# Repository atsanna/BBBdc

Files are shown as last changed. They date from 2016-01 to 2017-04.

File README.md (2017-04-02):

# BeagleBone Black Door Cape
This is a BeagleBone Black Cape designed for electronically locking or
unlocking a single door.  It can control either a 12V door strike or
a 12V door magnet.

You can order this PCB from oshpark here: https://oshpark.com/shared_projects/fA7vdbq6

The cape has the following features:
* Dual relays to ensure door is closed if a relay fails
* opto-isolated GPIO inputs for detecting door status and/or relay failure
* Jumpers for configuring door strike or door magnet (NO/NC)
* on-board voltage regulator so BBB can be powered via 12V
* connectors for two external software controlled 12V lamps
* LED indicators for 12V, 5V, relay engagement, and external lamps
* 24C256 EEPROM w/ address configurable via jumpers
* headers for an RPi/Arduino-compatible realtime clock module

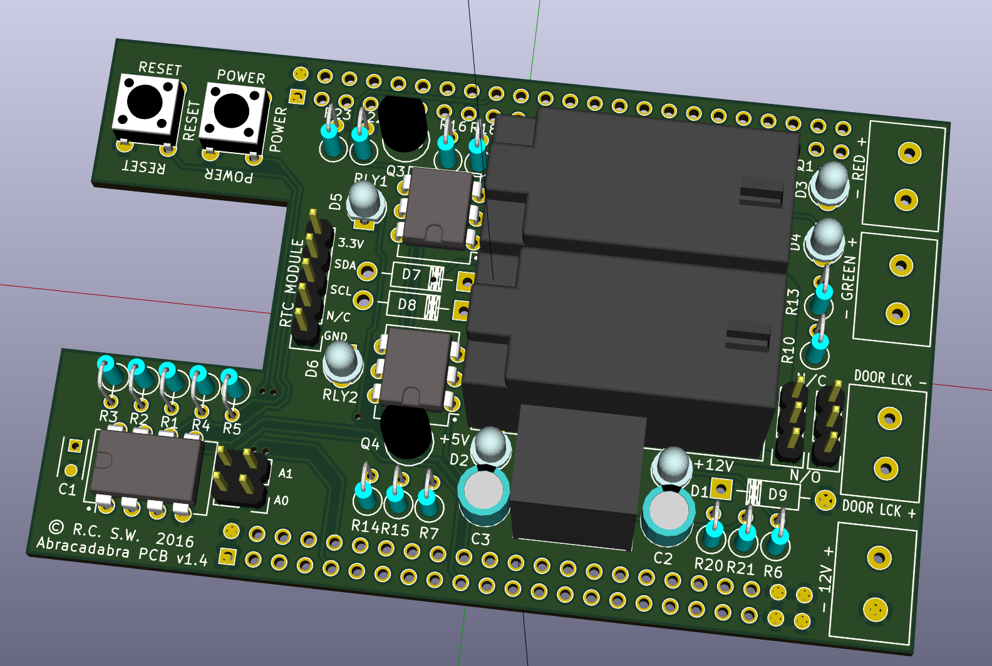
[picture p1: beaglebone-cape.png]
BareBone Cape


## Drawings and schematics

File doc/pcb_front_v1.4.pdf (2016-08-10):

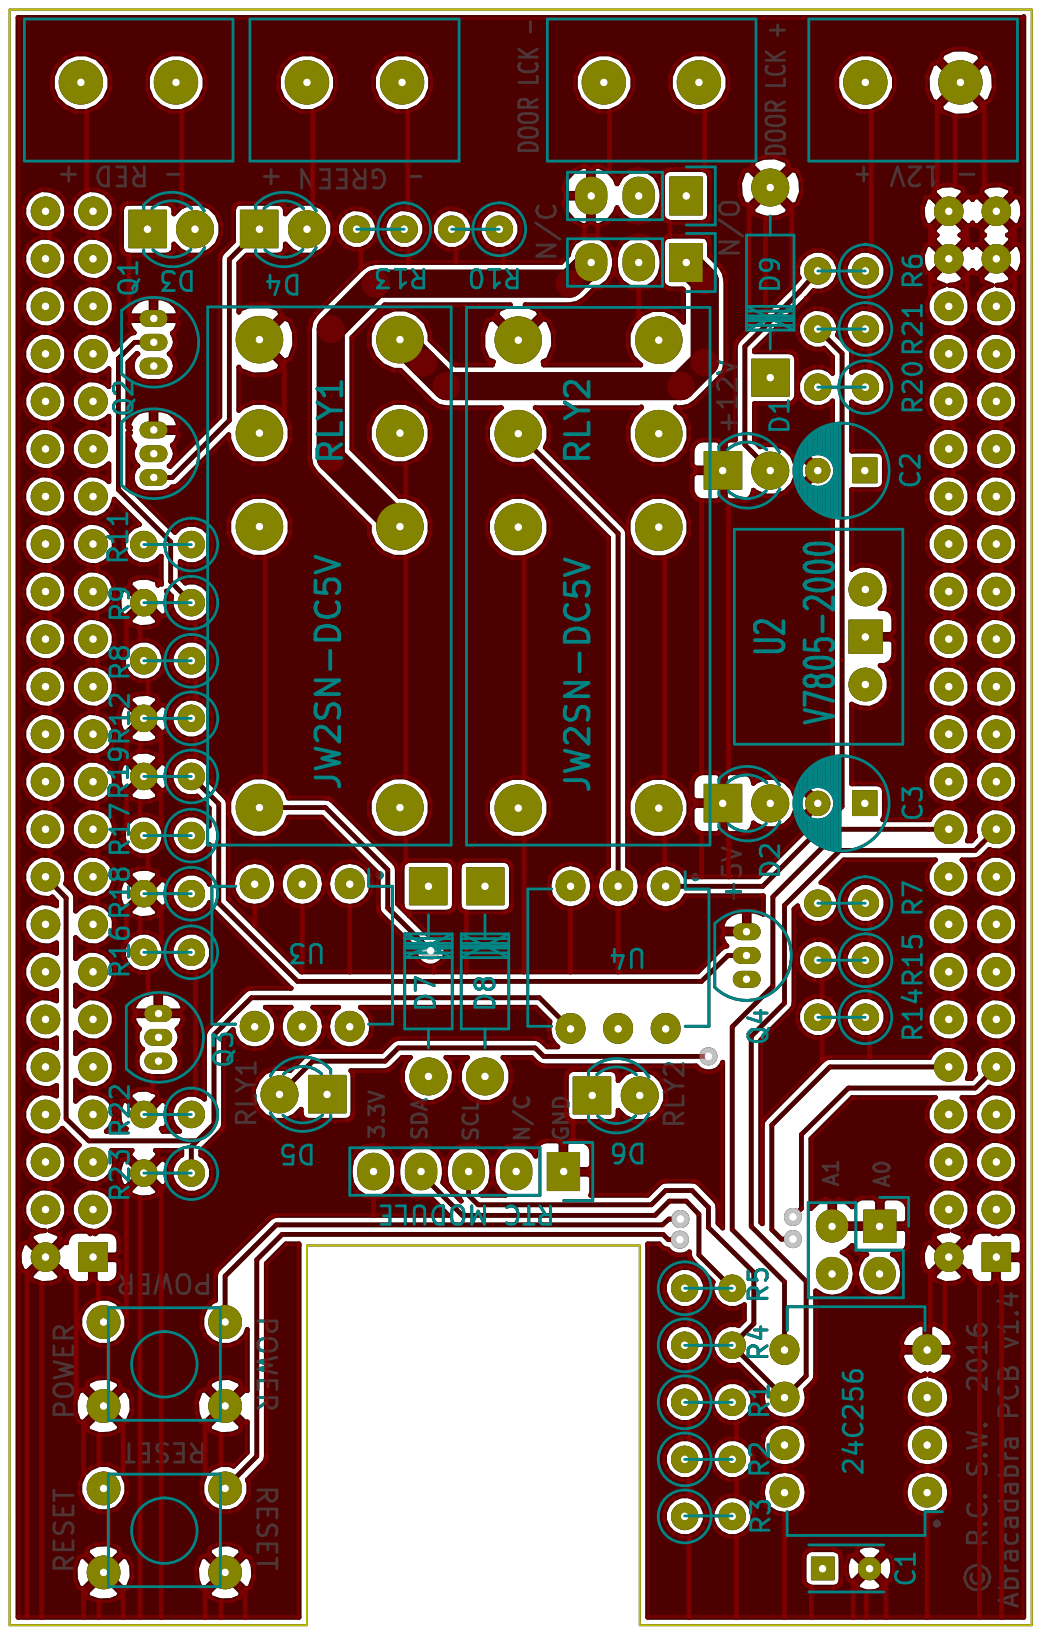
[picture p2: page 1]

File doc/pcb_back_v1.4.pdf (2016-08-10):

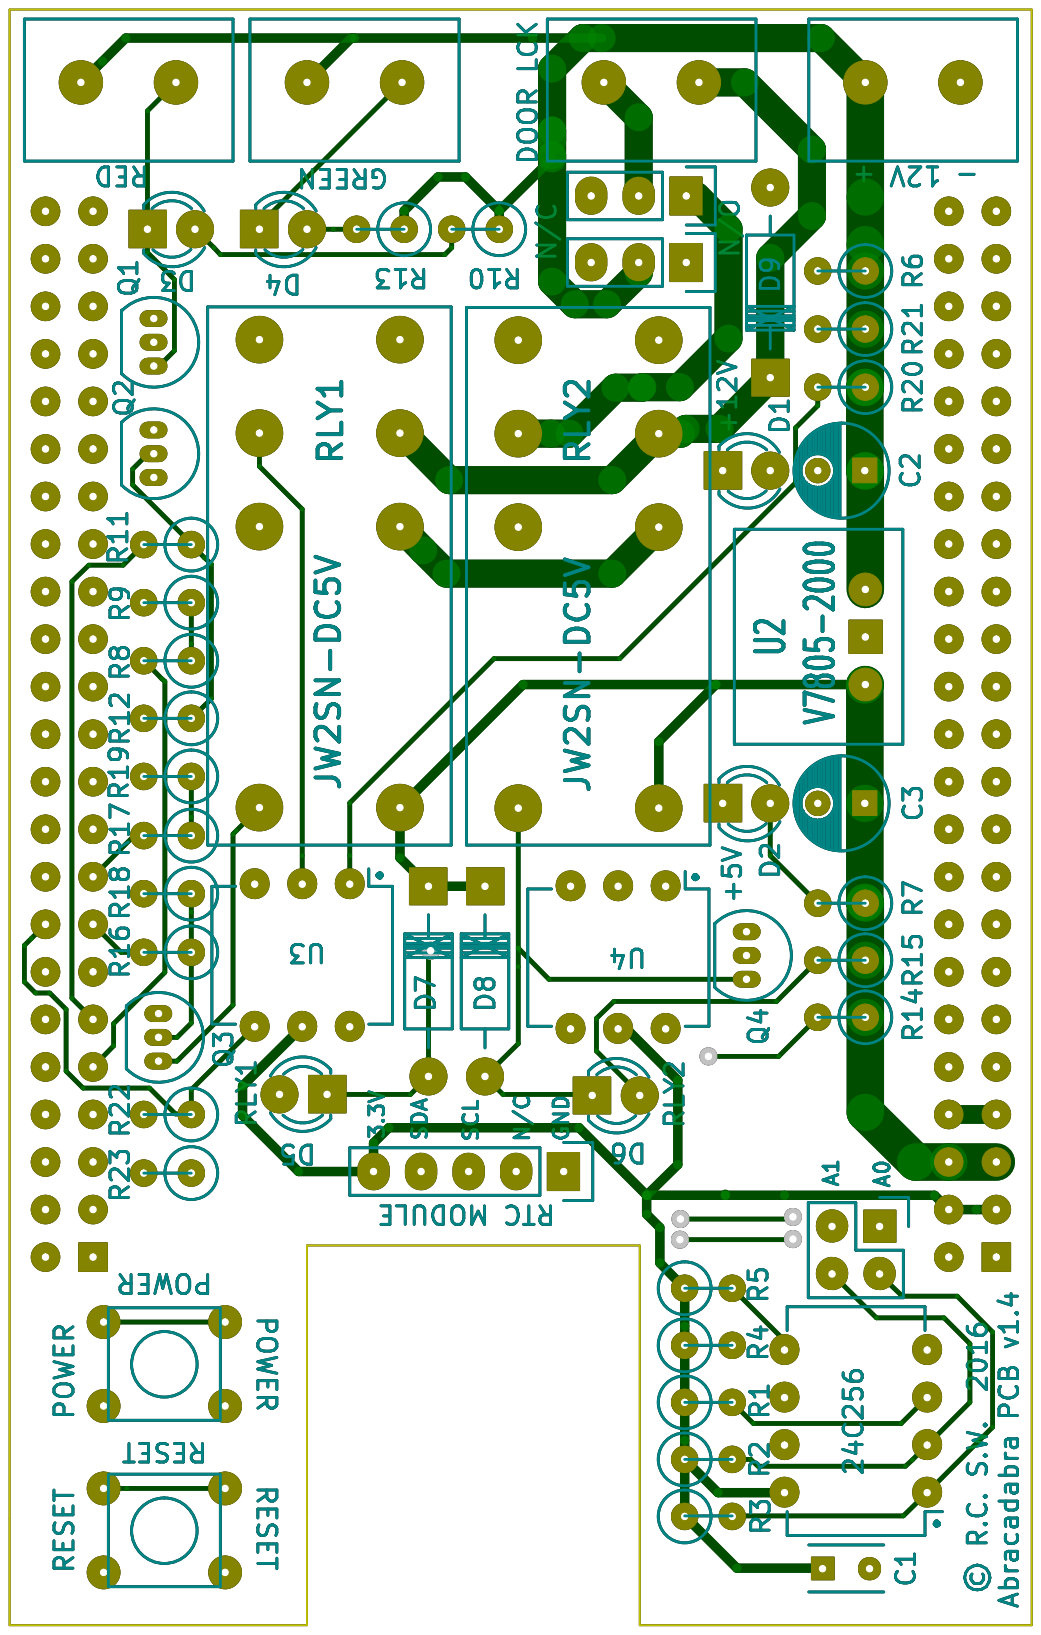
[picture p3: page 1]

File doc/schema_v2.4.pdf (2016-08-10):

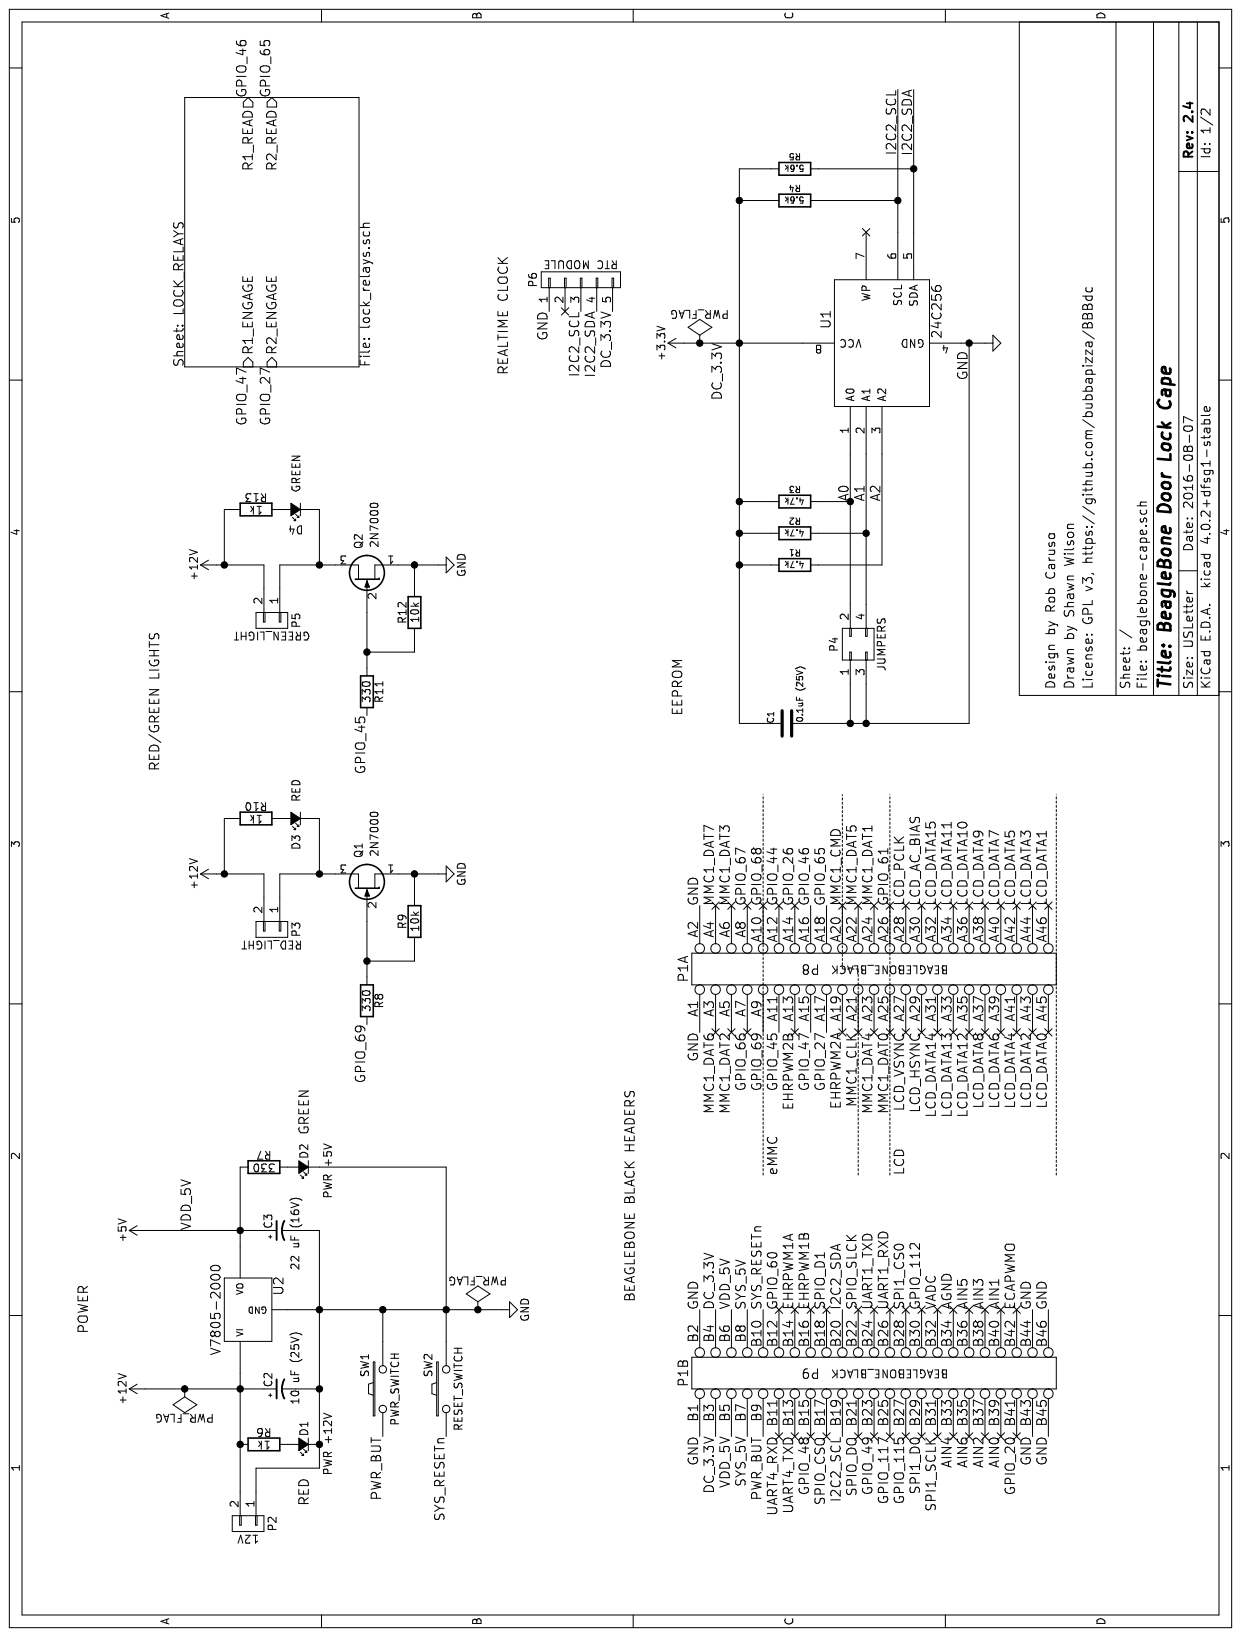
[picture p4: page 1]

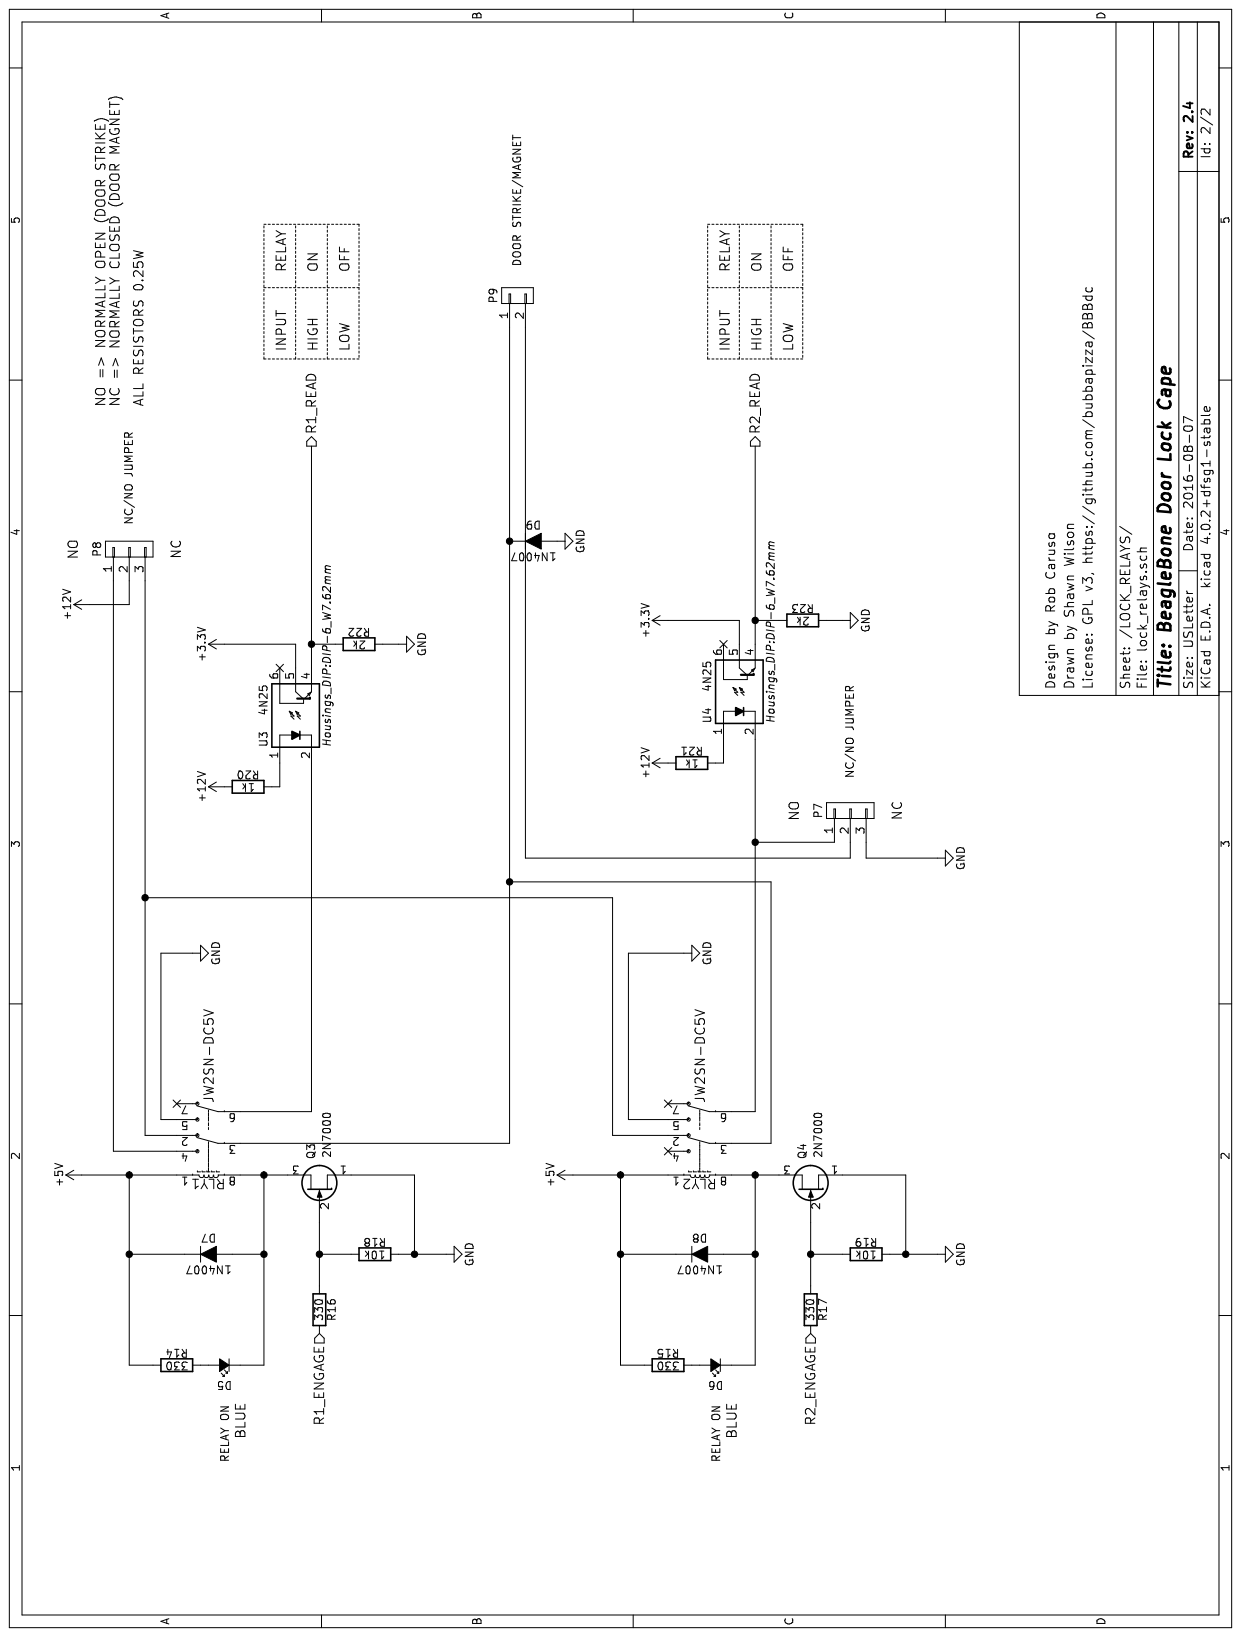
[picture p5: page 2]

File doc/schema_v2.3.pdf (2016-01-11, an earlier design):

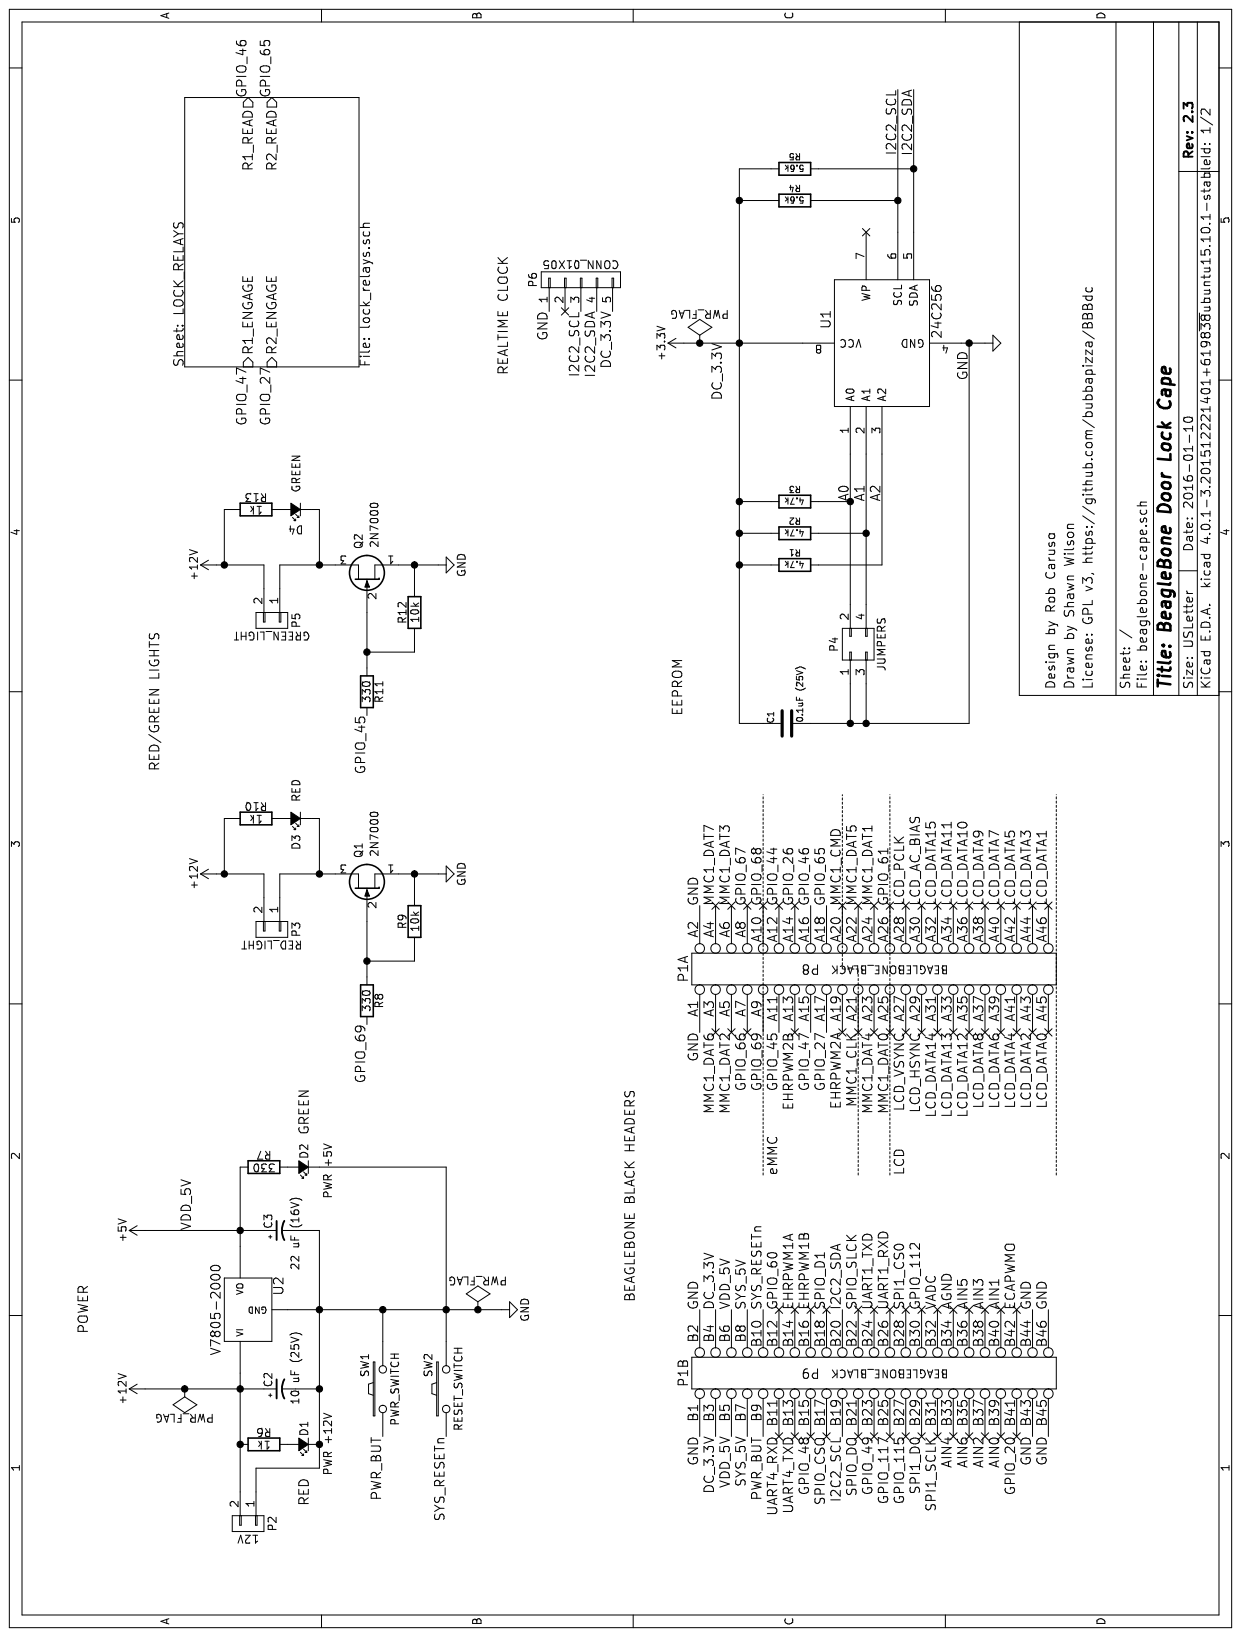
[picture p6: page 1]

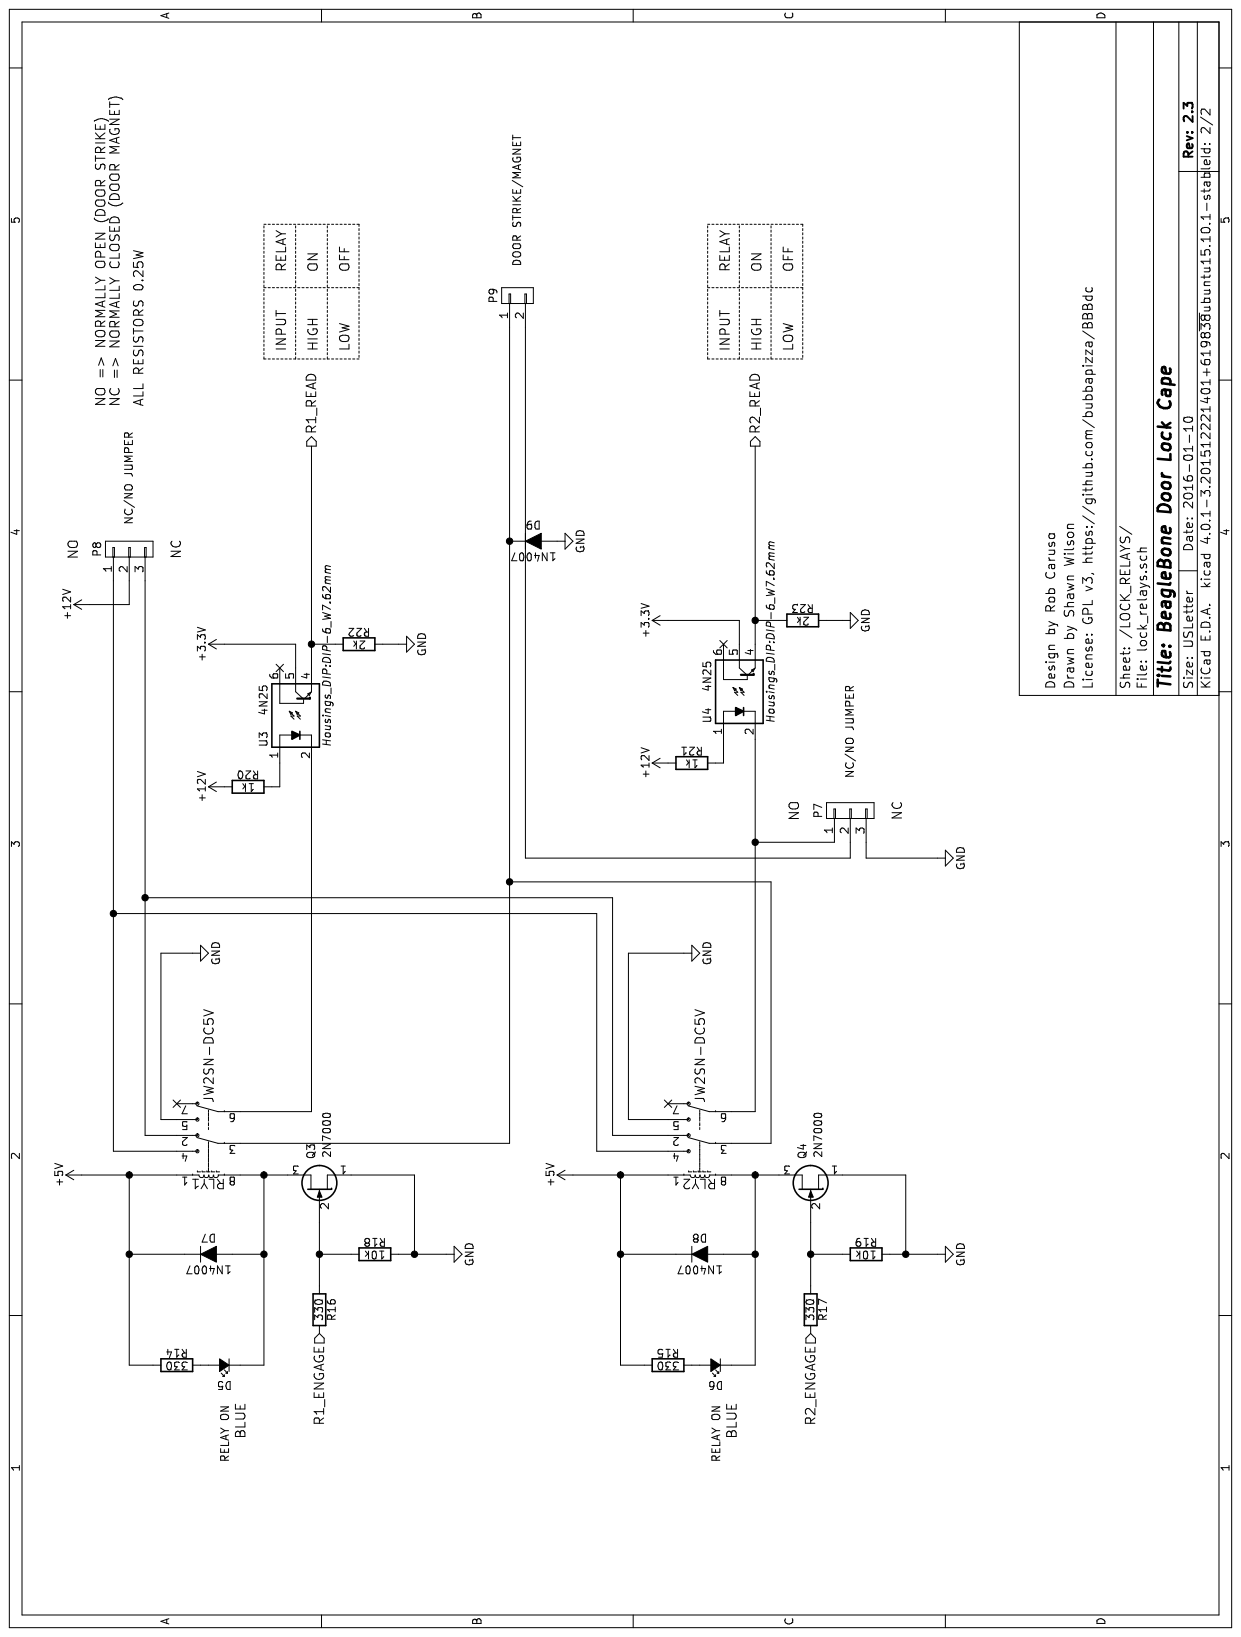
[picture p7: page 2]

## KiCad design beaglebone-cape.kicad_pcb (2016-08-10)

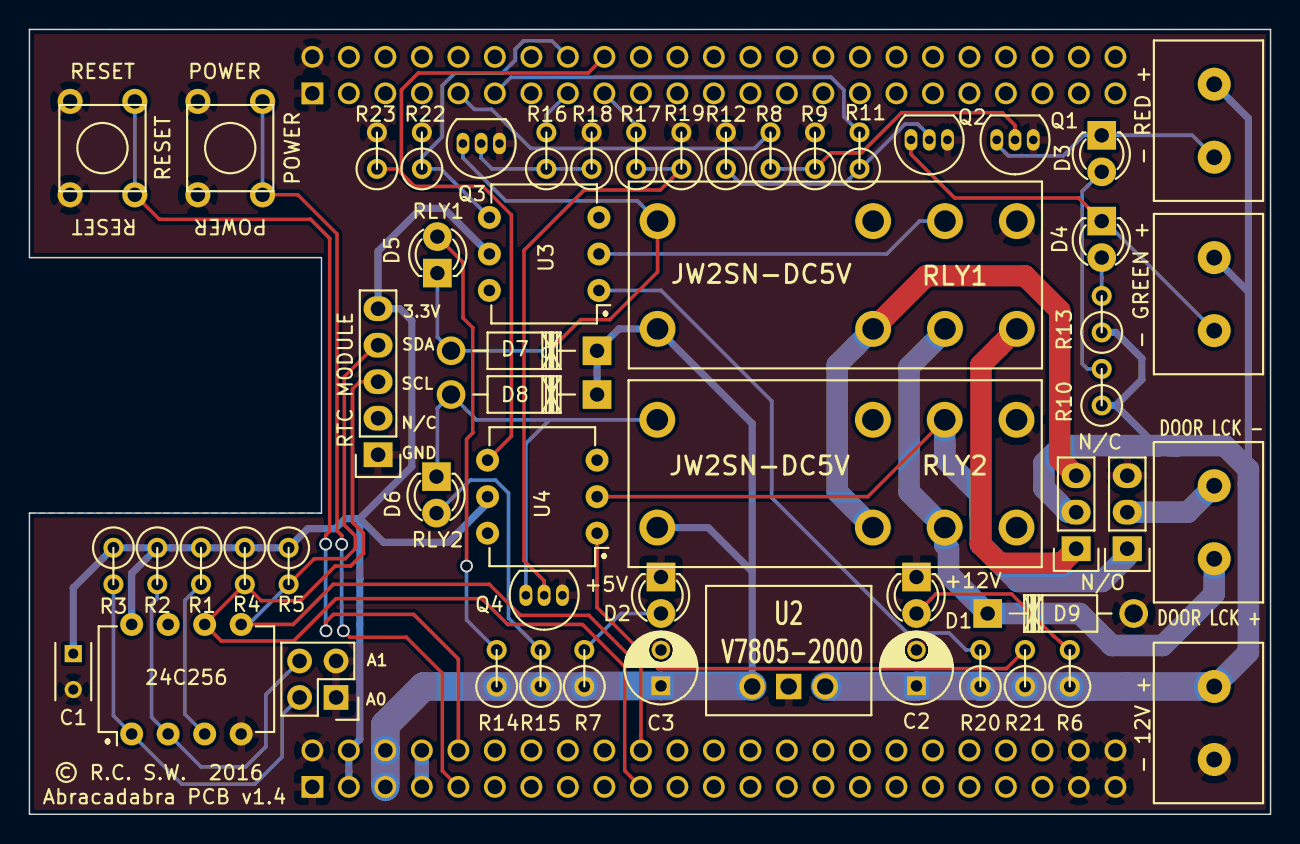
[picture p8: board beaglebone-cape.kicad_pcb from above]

Board: 2 copper layers, 86.4 x 54.6 mm, 56 parts (0 on the bottom side), 40 nets.

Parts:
C1: 0.1uF (25V); C_Rect_L4_W2.5_P2.5
C2: 10 uF (25V); C_Radial_D5_L6_P2.5
C3: 22 uF (16V); C_Radial_D5_L6_P2.5
D1: PWR +12V; LED-3MM
D2: PWR +5V; LED-3MM
D3: RED; LED-3MM
D4: GREEN; LED-3MM
D5, D6: RELAY ON; LED-3MM
D7, D8, D9: 1N4007; Diode_DO-41_SOD81_Horizontal_RM10
P1: BEAGLEBONE_BLACK; BEAGLEBONE_BLACK_NO_PERIMETER
P2: 12V; TERM_BLOCK_ED2609
P3: RED_LIGHT; TERM_BLOCK_ED2609
P4: JUMPERS; Pin_Header_Straight_2x02
P5: GREEN_LIGHT; TERM_BLOCK_ED2609
P6: RTC MODULE; Pin_Header_Straight_1x05
P7, P8: NC/NO JUMPER; Pin_Header_Straight_1x03
P9: DOOR STRIKE/MAGNET; TERM_BLOCK_ED2609
Q1, Q2, Q3, Q4: 2N7000; TO-92_Inline_Narrow_Oval
R1, R2, R3: 4.7k; R1
R4, R5: 5.6k; R1
R6, R10, R13, R20, R21: 1k; R1
R7, R8, R11, R14, R15, R16, R17: 330; R1
R9, R12, R18, R19: 10k; R1
R22, R23: 2k; R1
RLY1, RLY2: JW2SN-DC5V; Panasonic_JW
SW1: PWR_SWITCH; BUTTON_MJTP1230
SW2: RESET_SWITCH; BUTTON_MJTP1230
U1: 24C256; DIP-8_W7.62mm
U2: V7805-2000; V78XX-2000
U3, U4: 4N25; DIP-6_W7.62mm

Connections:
+3V3: C1.1, P1.B3, P1.B4, P6.5, R1.1, R2.1, R3.1, R4.1, R5.1, U1.8, U3.5, U4.5
+5V: C3.1, D7.1, D8.1, P1.B5, P1.B6, R7.1, R14.1, R15.1, RLY1.1, RLY2.1, U2.VO
+12V: C2.1, P2.2, P3.2, P5.2, P8.2, R6.1, R10.1, R13.1, R20.1, R21.1, U2.VI
/A0: P4.2, R3.2, U1.1
/A1: P4.4, R2.2, U1.2
/A2: R1.2, U1.3
/GPIO_45: P1.A11, R11.2
/GPIO_69: P1.A9, R8.2
/I2C2_SCL: P1.B19, P6.3, R4.2, U1.6
/I2C2_SDA: P1.B20, P6.4, R5.2, U1.5
/LOCK_RELAYS/R1_ENGAGE: P1.A15, R16.2
/LOCK_RELAYS/R1_READ: P1.A16, R22.1, U3.4
/LOCK_RELAYS/R2_ENGAGE: P1.A17, R17.2
/LOCK_RELAYS/R2_READ: P1.A18, R23.1, U4.4
/PWR_BUT: P1.B9, SW1.1
/SYS_5V: P1.B7, P1.B8
/SYS_RESETn: P1.B10, SW2.1
GND: C1.2, C2.2, C3.2, D1.1, D2.1, D9.2, P1.A1, P1.A2, P1.B1, P1.B2, P1.B43, P1.B44, P1.B45, P1.B46, P2.1, P4.1, P4.3, P6.1, P7.3, Q1.1, Q2.1, Q3.1, Q4.1, R9.2, R12.2, R18.2, R19.2, R22.2, R23.2, RLY1.5, RLY2.5, SW1.2, SW2.2, U1.4, U2.GND
unnamed: D1.2, R6.2
unnamed: D2.2, R7.2
unnamed: D3.1, P3.1, Q1.3
unnamed: D3.2, R10.2
unnamed: D4.1, P5.1, Q2.3
unnamed: D4.2, R13.2
unnamed: D5.1, D7.2, Q3.3, RLY1.8
unnamed: D5.2, R14.2
unnamed: D6.1, D8.2, Q4.3, RLY2.8
unnamed: D6.2, R15.2
unnamed: D9.1, P9.1, RLY1.3, RLY2.3
unnamed: P7.1, RLY2.6, U4.2
unnamed: P7.2, P9.2
unnamed: P8.1, RLY1.4
unnamed: P8.3, RLY1.2, RLY2.2
unnamed: Q1.2, R8.1, R9.1
unnamed: Q2.2, R11.1, R12.1
unnamed: Q3.2, R16.1, R18.1
unnamed: Q4.2, R17.1, R19.1
unnamed: R20.2, U3.1
unnamed: R21.2, U4.1
unnamed: RLY1.6, U3.2

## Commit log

2015-11-08 Created power schematic
    [beaglebone-cape.sch]
2015-11-08 Got everything done except lock relays
    [beaglebone-cape.sch]
2015-11-08 Clean up schematic
    [beaglebone-cape.sch]
2015-11-12 Added relay library, got locks drawn to the point where I have no idea how to hook things up
    [beaglebone-cape.sch]
2015-11-14 Lock relay page looks done, still needs circuit check
    [lock_relays.sch]
2015-11-18 Fixed BBB header labels, added some more lights and feed some gpio pins to detect lock status.
    [beaglebone-cape.sch, lock_relays.sch]
2015-11-18 Added relay data sheet
2015-11-18 Added a netlist and started fixing rule check errors
    [beaglebone-cape.sch, lock_relays.sch]
2015-11-25 changed version
    [beaglebone-cape.sch, lock_relays.sch]
2015-11-26 schematic version 2.0 - redrawn w/ dpdt relays
    [beaglebone-cape.sch, lock_relays.sch]
2015-11-28 Added opto-isolators, get ERC to pass, fix DPDT relay pictures
    [beaglebone-cape.sch, lock_relays.sch]
2015-11-28 Added relay datasheet to schematic
    [lock_relays.sch]
2015-11-29 Working towards v2.2
    [beaglebone-cape.sch, lock_relays.sch]
2015-11-29 Finished schematic changes for v2.2
    [beaglebone-cape.sch, lock_relays.sch]
2015-11-29 Added footprints for relays and switching regulator
2015-12-01 Added v2.2 schematic and the module libraries to the fp-lib-table
2015-12-04 built a net list, probably wrong parts but it's a start
    [beaglebone-cape.sch, lock_relays.sch]
2015-12-04 not sure what I just did
    [beaglebone-cape.kicad_pcb]
2015-12-07 Imported parts to pcbnew but its a mess
    [beaglebone-cape.kicad_pcb]
2015-12-07 Ironed out footprints with Rob, started placing stuff
    [beaglebone-cape.kicad_pcb, beaglebone-cape.sch, lock_relays.sch]
2015-12-07 Moved a bunch of footprints around
    [beaglebone-cape.kicad_pcb]
2015-12-07 unbelievably managed to squeeze everything on the board
    [beaglebone-cape.kicad_pcb]
2015-12-07 tweaking of component placement on board
    [beaglebone-cape.kicad_pcb]
2015-12-19 Added custom footprints & data sheets
    [beaglebone-cape.kicad_pcb]
2015-12-19 Placed new footprints, re-arrange things to make power layout better.
    [beaglebone-cape.kicad_pcb, beaglebone-cape.sch, lock_relays.sch]
2015-12-20 Working on power tracks
    [beaglebone-cape.kicad_pcb]
2015-12-20 Finished first crack at laying power
    [beaglebone-cape.kicad_pcb]
2015-12-20 Added date and versioning to pcb
    [beaglebone-cape.kicad_pcb]
2015-12-22 Changed all power track widths to 2mm, made slight path change to 5V net
    [beaglebone-cape.kicad_pcb]
2015-12-28 layin pipe
    [beaglebone-cape.kicad_pcb]
2015-12-28 Still working on tracks
    [beaglebone-cape.kicad_pcb]
2015-12-28 Got DRC check to pass on pcb
    [beaglebone-cape.kicad_pcb]
2015-12-28 Cleaned up silk screening, adjust module alignment
    [beaglebone-cape.kicad_pcb]
2015-12-29 Updated documentation, tag as v1.11
    [beaglebone-cape.kicad_pcb]
2015-12-30 Tweaking traces
    [beaglebone-cape.kicad_pcb]
2015-12-30 pcb - about to change jumpers. Most other fixes are done
    [beaglebone-cape.kicad_pcb]
2015-12-30 Finished moving jumpers together on pcb
    [beaglebone-cape.kicad_pcb]
2015-12-30 Finished polishing up latest changes while sitting in the coffee exchange
    [beaglebone-cape.kicad_pcb]
2015-12-31 Finalized pcb v1.2
    [beaglebone-cape.kicad_pcb]
2016-01-03 Moved panasonic and relay modules into pretty local library. Added 3d files for button
    [beaglebone-cape.kicad_pcb]
2016-01-03 replaced the 3d models for buttons
    [beaglebone-cape.kicad_pcb]
2016-01-03 Added 3d model for Panasonic relays, update changelog, change version#
    [beaglebone-cape.kicad_pcb]
2016-01-03 Change silkscreen labels for power & relay LEDs
    [beaglebone-cape.kicad_pcb]
2016-01-09 flipped q3 around 180 deg.
    [beaglebone-cape.kicad_pcb]
2016-01-09 Changed track widths from 2.0 to 1.5
    [beaglebone-cape.kicad_pcb]
2016-01-09 Bumped up track width for 3.3V rail
    [beaglebone-cape.kicad_pcb]
2016-01-09 Added TODO list, almost there
    [beaglebone-cape.kicad_pcb]
2016-01-09 Added silkscreen comments, copyright
    [beaglebone-cape.kicad_pcb]
2016-01-10 Flipped RTC module, rearranged resistors R1-R5, add A0 A1 to silk screen for jumpers
    [beaglebone-cape.kicad_pcb, beaglebone-cape.sch]
2016-01-10 fixed EEPROM addressing in schmeatic, working on routing pcb now
    [beaglebone-cape.kicad_pcb]
2016-01-11 Finished pcb v1.3 and schematic v2.3
    [beaglebone-cape.kicad_pcb, beaglebone-cape.sch, lock_relays.sch]
2016-01-13 tweaking silk screen, checked dimensions, ready for mfg
    [beaglebone-cape.kicad_pcb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]
2016-01-27 Added a couple more things TODO
2016-08-04 renamed hocuspocus library to abracadabra, fixed mask on panasonic relay library module, added R23, fixed wiring for relays
    [beaglebone-cape.kicad_pcb, lock_relays.sch]
2016-08-04 fixed solder mask on bottom relays
    [beaglebone-cape.kicad_pcb]
2016-08-05 fixed relay and terminal block
    [beaglebone-cape.kicad_pcb]
2016-08-07 Almost fixed all pcb footprints so exchanging footprints w/ the schematic doesn't screw things up.
    [beaglebone-cape.kicad_pcb, beaglebone-cape.sch, lock_relays.sch]
2016-08-07 Finished fixing footprints, added dots to chips, added more version info to silkscreen, updated TODO. Only thing left is to move top row of resistors closer to RLY1.
    [beaglebone-cape.kicad_pcb, beaglebone-cape.sch, lock_relays.sch]
2016-08-10 Moved top row of resistors away from headers to make it easier to solder, did some cleanup of silkscreen labelling.
    [beaglebone-cape.kicad_pcb]
2016-08-10 Updated documentation for pcb v1.4 and schema v2.4
    [beaglebone-cape.kicad_pcb, lock_relays.sch]
2016-08-10 Added polarity to terminal blocks on front silkscreen, added picture for readme.
    [beaglebone-cape.kicad_pcb]
2016-08-10 Forgot to save door lock silk screen changes
    [beaglebone-cape.kicad_pcb]
2016-08-11 Deleted old gerbers
    [beaglebone-cape-B.Cu.gbl, beaglebone-cape-B.Mask.gbs, beaglebone-cape-B.SilkS.gbo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]

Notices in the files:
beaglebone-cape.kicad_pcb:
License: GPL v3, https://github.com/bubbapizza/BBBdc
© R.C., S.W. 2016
